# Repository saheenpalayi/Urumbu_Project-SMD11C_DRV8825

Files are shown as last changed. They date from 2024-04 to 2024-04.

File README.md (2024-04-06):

# Urumbu_Project-SMD11C_DRV8825

I wanted to try out the Urumbu Project by Neil Gershenfeld, at SuperFablab Kerala, Kochi but, unfortunately, we don't have a 5V stepper driver in our inventory, so thought of creating a version of the Urumbu project with SAMD11C and DRV8825 motor driver.

## Design
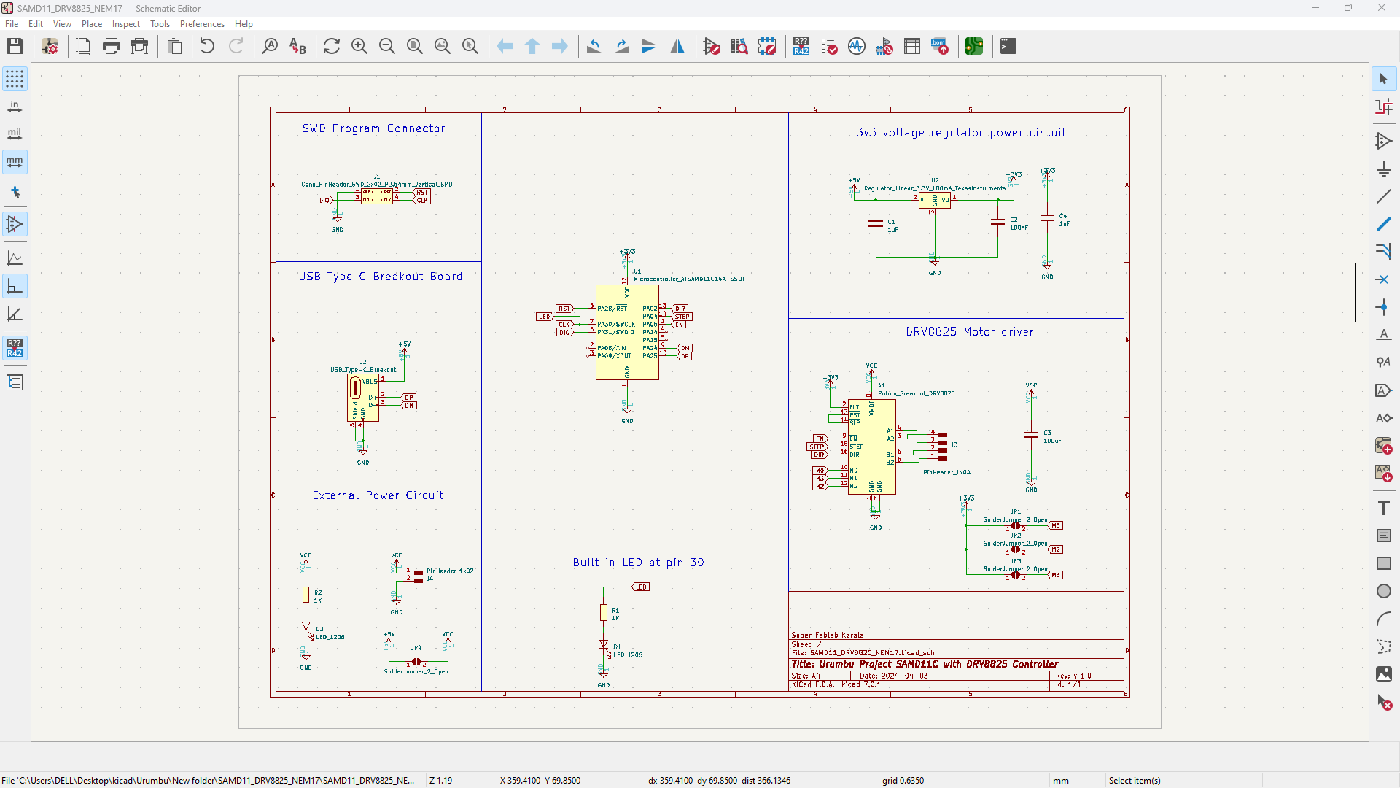
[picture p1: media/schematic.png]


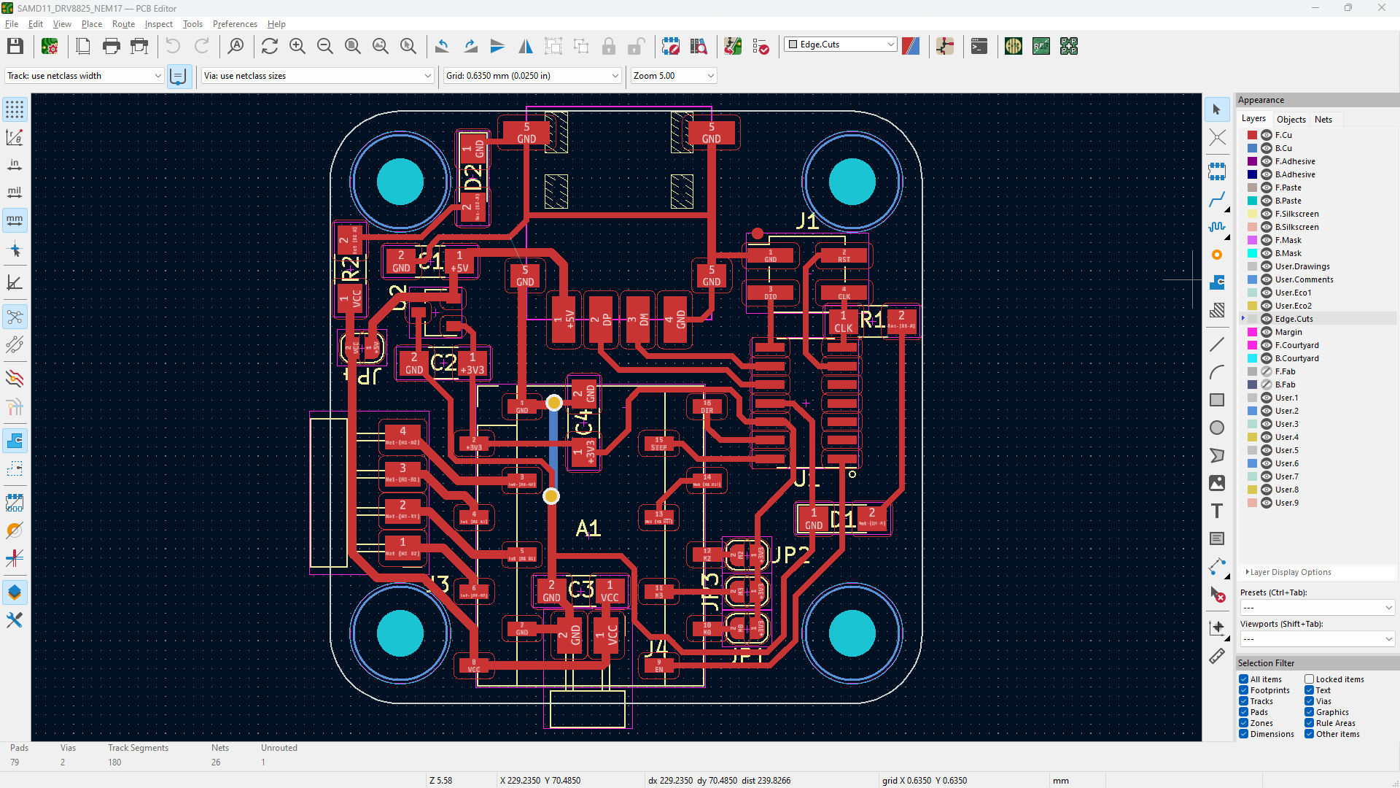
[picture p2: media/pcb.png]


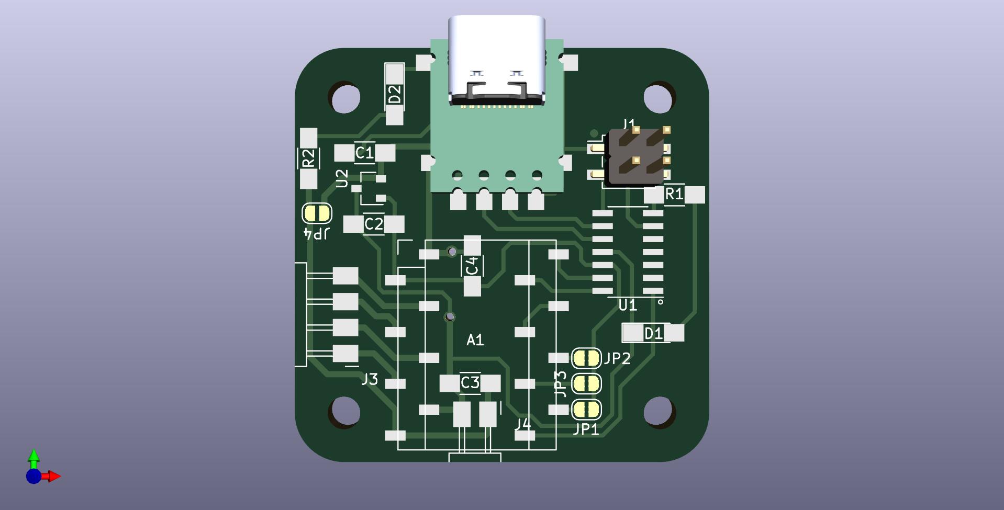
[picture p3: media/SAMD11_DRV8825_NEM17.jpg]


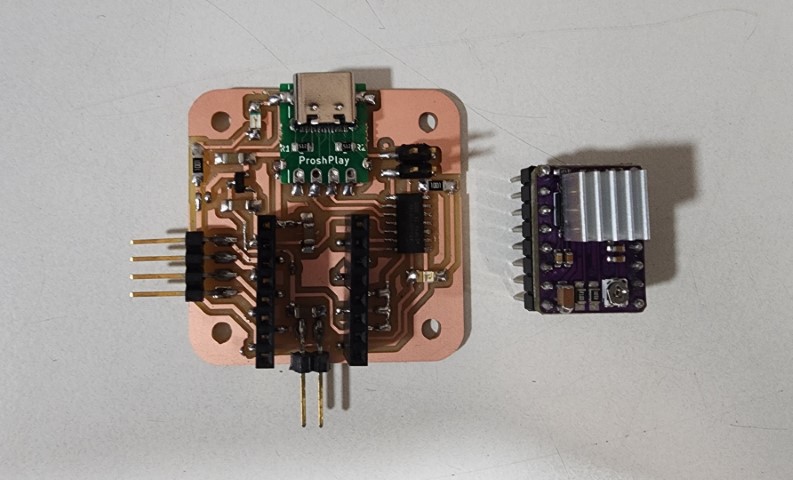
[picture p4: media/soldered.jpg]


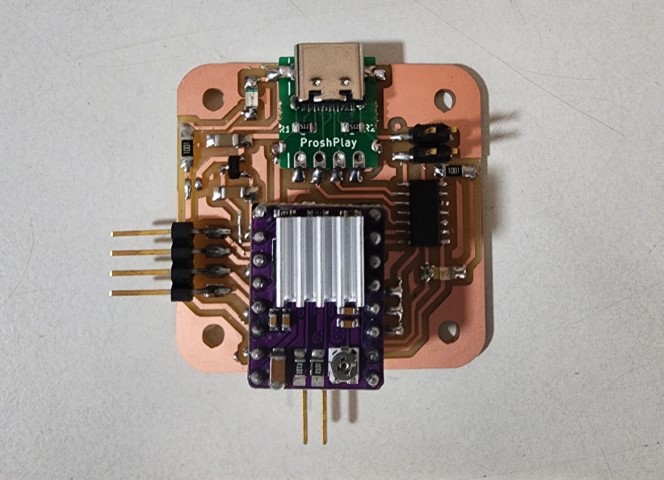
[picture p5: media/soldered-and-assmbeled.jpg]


## Testing

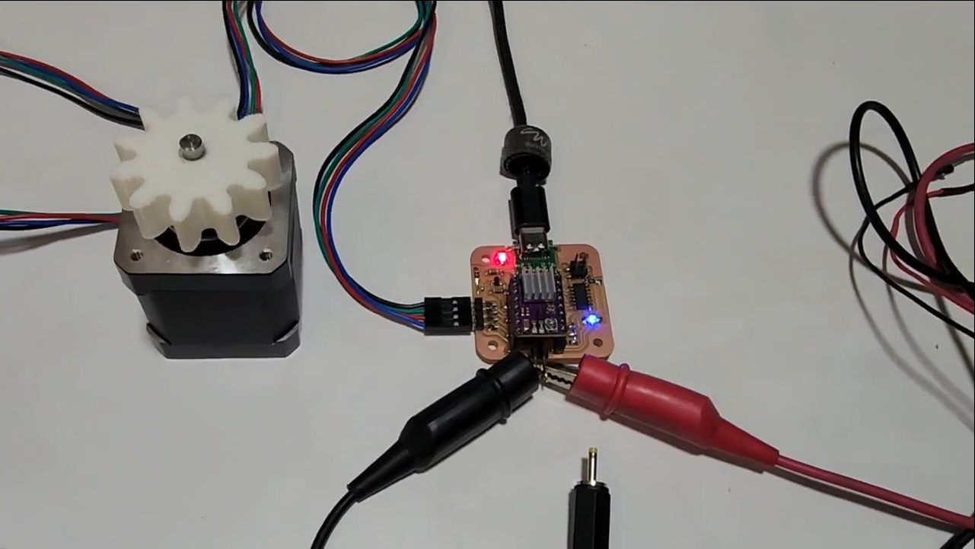
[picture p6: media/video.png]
Watch the video (https://gitlab.fabcloud.org/saheen.palayi/urumbu_project-smd11c_drv8825/-/raw/main/media/Test.mp4)


## Downloads
- [SAMD11_DRV8825_NEM17.pdf](<design files/Kicad Files/SAMD11_DRV8825_NEM17.pdf>)
- [SAMD11_DRV8825_NEM17.step](<design files/Kicad Files/SAMD11_DRV8825_NEM17.step>)
- [gerber.zip](<design files/Gerber Files/gerber.zip>)
- [Firmware](firmware/urumbu-d11c-drv8825/urumbu-d11c-drv8825.ino)

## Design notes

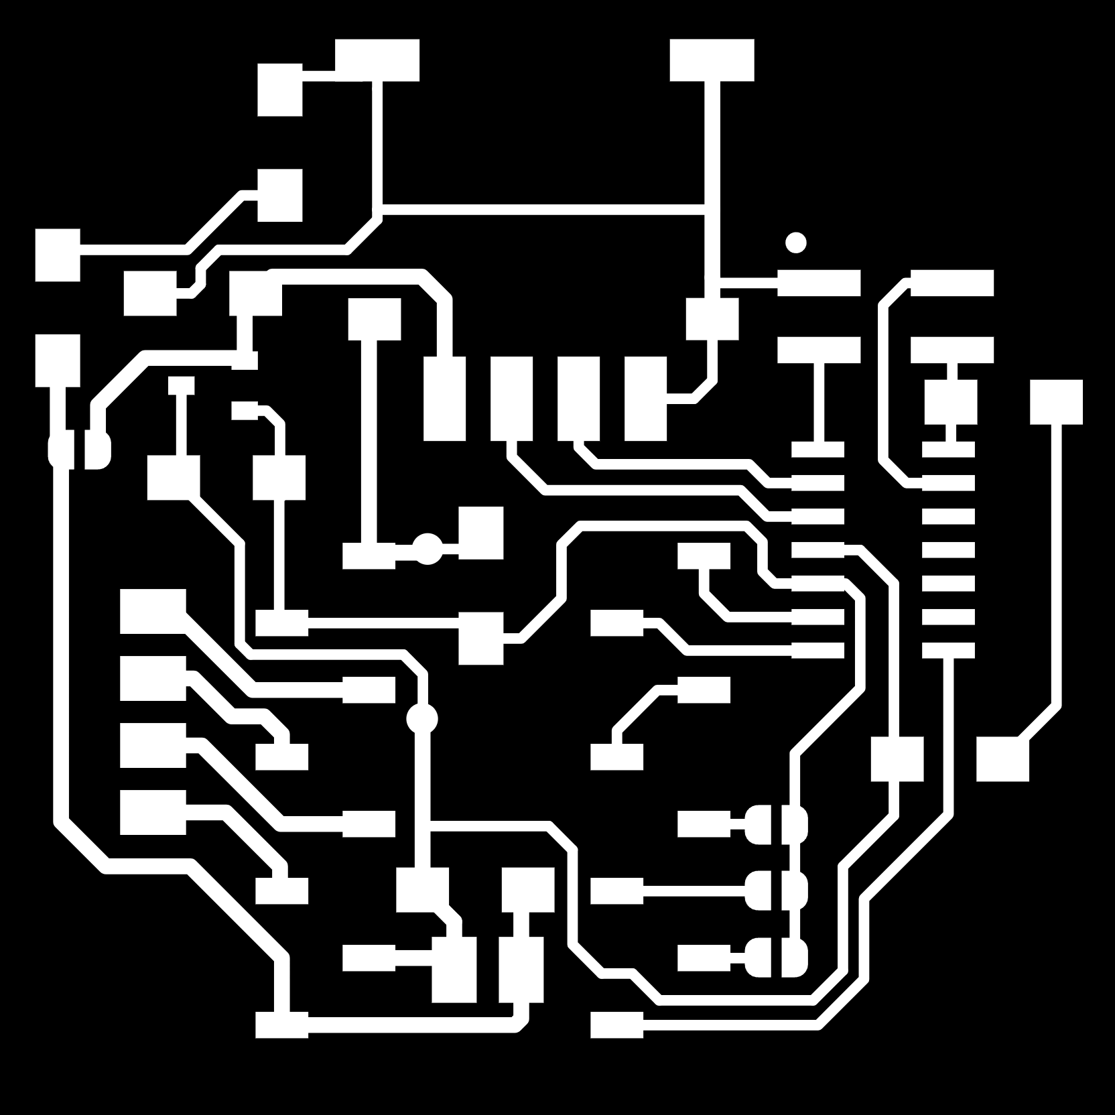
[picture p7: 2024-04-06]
design files/FAB Milling Files/traces.png

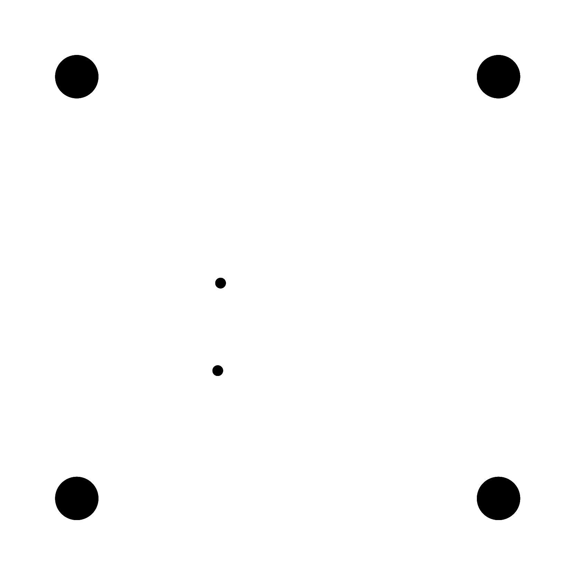
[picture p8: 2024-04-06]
design files/FAB Milling Files/drills.png

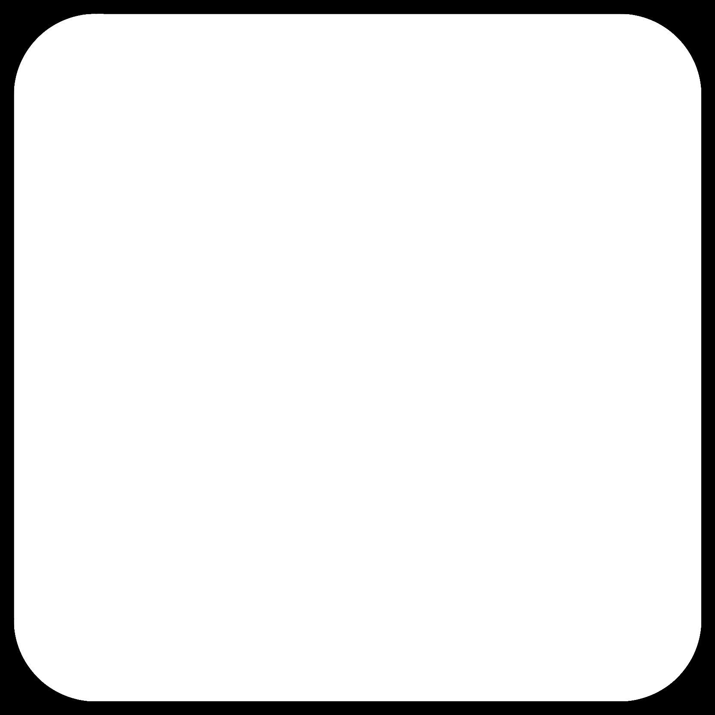
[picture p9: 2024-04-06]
design files/FAB Milling Files/outline.png

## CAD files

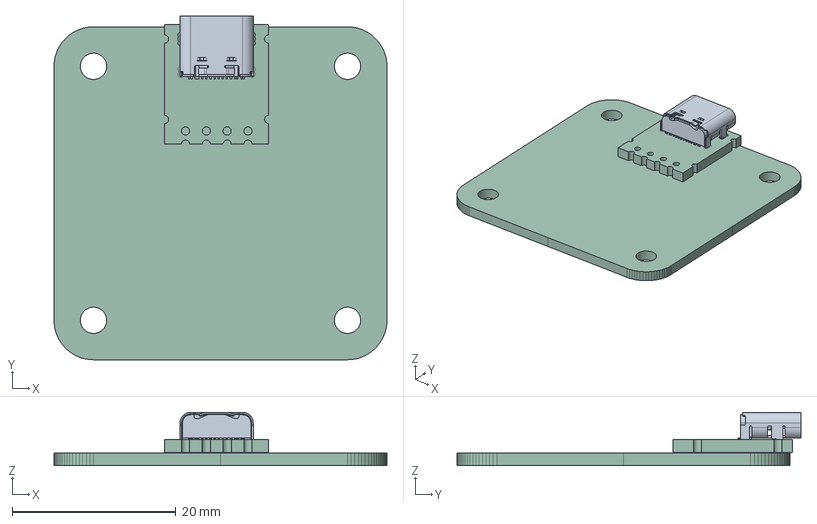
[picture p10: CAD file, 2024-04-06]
design files/Kicad Files/SAMD11_DRV8825_NEM17.step
40.6 x 41.9 x 6.52 mm
PCB

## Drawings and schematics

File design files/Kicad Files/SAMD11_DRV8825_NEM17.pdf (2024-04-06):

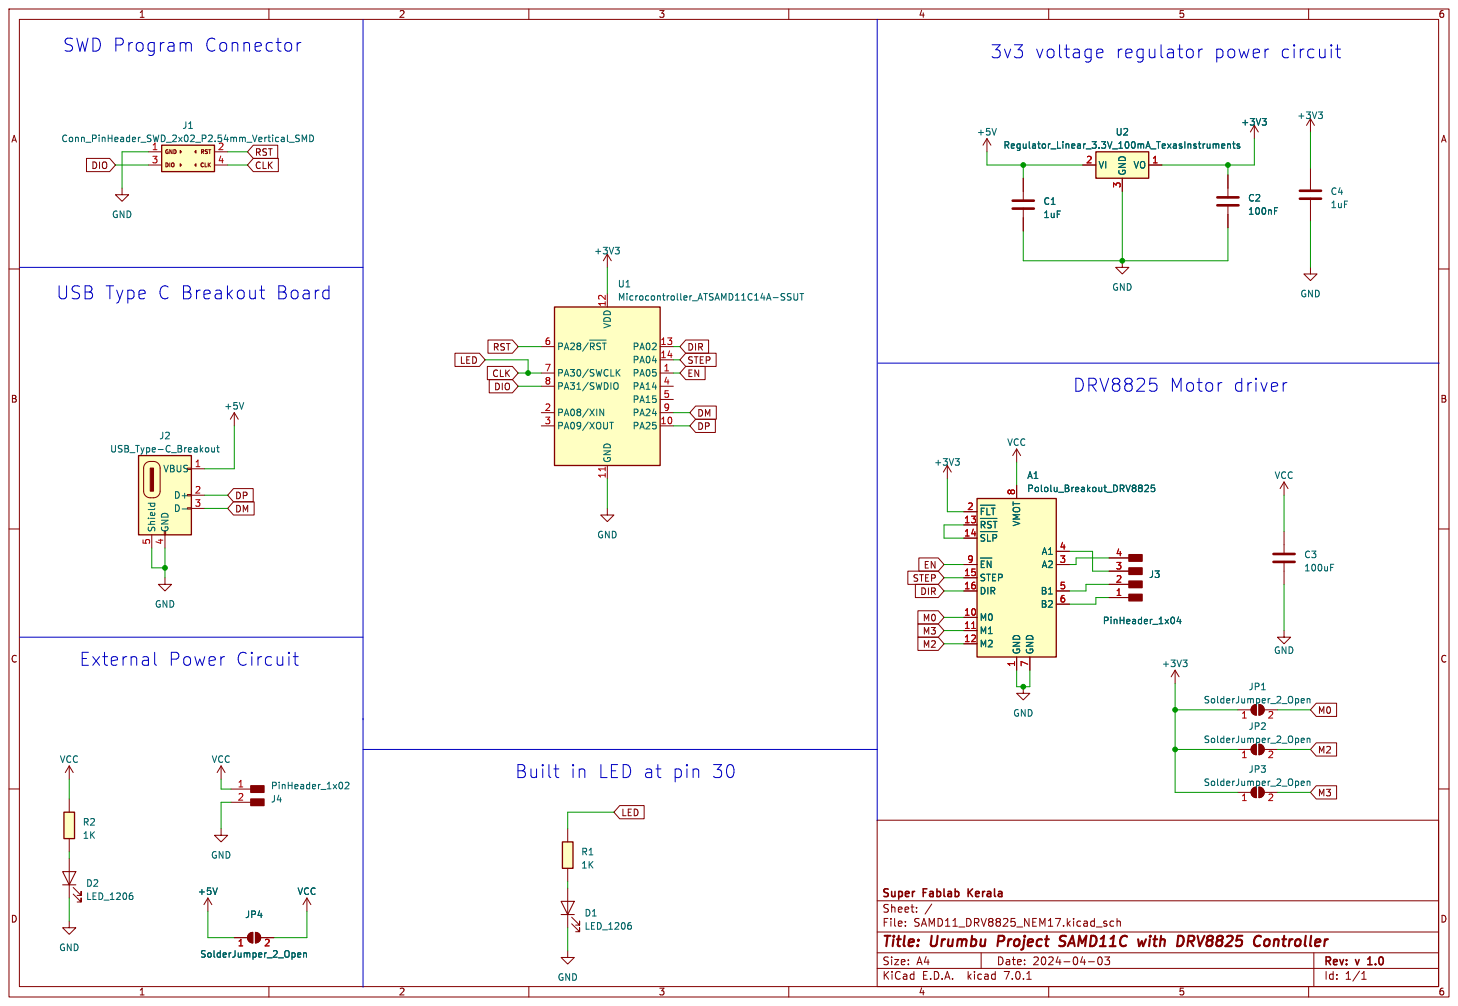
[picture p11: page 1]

USB Type C Breakout Board

1 M0 10 M1 11 M2 12 ~{RST} 13 ~{SLP} 14 STEP 15 DIR 16 ~{FLT} 2 A2 3 A1 4 B1 5 B2 6 GND

Built in LED at pin 30

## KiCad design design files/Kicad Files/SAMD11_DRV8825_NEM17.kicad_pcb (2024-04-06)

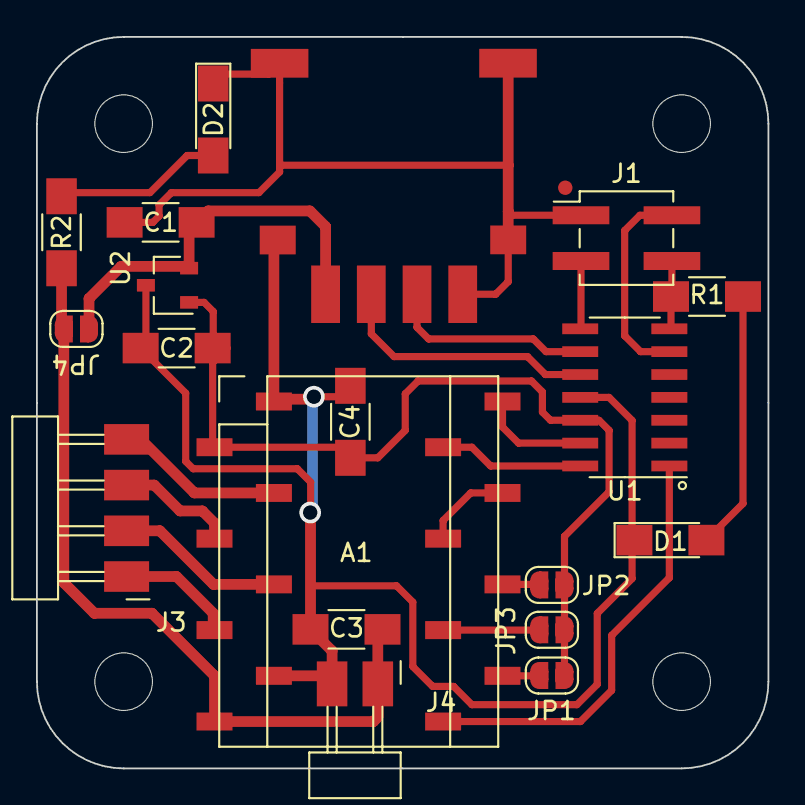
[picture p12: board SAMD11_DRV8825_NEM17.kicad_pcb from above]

Board: 2 copper layers, 40.6 x 40.6 mm, 19 parts (0 on the bottom side), 22 nets.

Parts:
A1: Pololu_Breakout_DRV8825; DRV8825_SMD_pinheader_breakout
C1, C2, C3, C4: C_1206
D1, D2: LED_1206
J1: Conn_PinHeader_SWD_2x02_P2.54mm_Vertical_SMD; PinHeader_2x02_P2.54mm_Vertical_SMD
J2: USB_Type-C_Breakout; ProshPlay-Type-C-breakout-board
J3: Conn_PinHeader_1x04_P2.54mm_Horizontal_SMD; PinHeader_1x04_P2.54mm_Horizontal_SMD
J4: Conn_PinHeader_1x02_P2.54mm_Horizontal_SMD; PinHeader_1x02_P2.54mm_Horizontal_SMD
JP1, JP2, JP3, JP4: SolderJumper_2_Open; SolderJumper-2_P1.3mm_Open_RoundedPad1.0x1.5mm_0.4mm
R1, R2: R_1206
U1: Microcontroller_ATSAMD11C14A-SSUT; SOIC-14_3.9x8.7mm_P1.27mm
U2: Regulator_Linear_3.3V_100mA_TexasInstruments; SOT-23-3

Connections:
+3V3: A1.2 (~FLT), C2.1, C4.1, JP1.1 (A), JP2.1 (A), JP3.1 (A), U1.12 (VDD), U2.1 (VO)
+5V: C1.1, J2.1 (VBUS), JP4.1 (A), U2.2 (VI)
CLK: J1.4, R1.1, U1.7 (PA30/SWCLK)
DIO: J1.3, U1.8 (PA31/SWDIO)
DIR: A1.16 (DIR), U1.13 (PA02)
DM: J2.3 (D-), U1.9 (PA24)
DP: J2.2 (D+), U1.10 (PA25)
EN: A1.9 (~EN), U1.1 (PA05)
GND: A1.1 (GND), A1.7 (GND), C1.2, C2.2, C3.2, C4.2, D1.1 (K), D2.1 (K), J1.1, J2.4 (GND), J2.5 (Shield), J4.2, U1.11 (GND), U2.3 (GND)
M0: A1.10 (M0), JP1.2 (B)
M2: A1.12 (M2), JP2.2 (B)
M3: A1.11 (M1), JP3.2 (B)
unnamed: A1.4 (A1), J3.3
unnamed: A1.3 (A2), J3.4
unnamed: A1.5 (B1), J3.2
unnamed: A1.6 (B2), J3.1
unnamed: A1.13 (~RST), A1.14 (~SLP)
unnamed: D1.2 (A), R1.2
unnamed: D2.2 (A), R2.2
RST: J1.2, U1.6 (PA28/~RST)
STEP: A1.15 (STEP), U1.14 (PA04)
VCC: A1.8 (VMOT), C3.1, J4.1, JP4.2 (B), R2.1

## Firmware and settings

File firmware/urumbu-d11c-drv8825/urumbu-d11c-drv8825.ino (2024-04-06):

//
// urumbu-d11c-drv8825.ino
//
// serial step-and-direction
//
// Neil Gershenfeld 4/11/21
// Quentin Bolsee 12/7/21 : add button
// Saheen Palayi 06/04/2024 : removed microstepping and added LED, 
//
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


#define Address "000" // change address here

#define LED 30
#define EN 5
#define DIR 2
#define STEP 4
#define BUTTON 31


void setup() {
  SerialUSB.begin(0);

  pinMode(LED, OUTPUT);
  pinMode(EN, OUTPUT);
  pinMode(STEP, OUTPUT);
  pinMode(DIR, OUTPUT);
  pinMode(BUTTON, INPUT_PULLUP);

  digitalWrite(LED, HIGH);
  digitalWrite(EN, HIGH);
  digitalWrite(STEP, LOW);
  digitalWrite(DIR, LOW);
}

void loop() {
  if (SerialUSB.available()) {
    char c = SerialUSB.read();
    if (c == 'f') {
      digitalWrite(DIR, HIGH);
      digitalWrite(STEP, HIGH);
      digitalWrite(LED, HIGH);
      delayMicroseconds(2);
      digitalWrite(STEP, LOW);
      digitalWrite(LED, LOW);
    } else if (c == 'r') {
      digitalWrite(DIR, LOW);
      digitalWrite(LED, HIGH);
      delayMicroseconds(2);
      digitalWrite(STEP, LOW);
      digitalWrite(LED, LOW);
    } else if (c == '?') {
      // reply with button value
      int btn = digitalRead(BUTTON);
      SerialUSB.write(btn ? '1' : '0');
    } else if (c == '@') {
      SerialUSB.write(Address); 
    }
  }
}

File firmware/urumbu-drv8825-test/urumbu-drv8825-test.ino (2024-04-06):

//
// urumbu-drv8825-test.ino
//
// DRV8825-D11C stepper test code
//
// Saheen Palayi 06/04/24
//
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

#define LED 30
#define EN 5
#define DIR 2
#define STEP 4

void setup() {
  pinMode(LED, OUTPUT);   // LED pin as output
  pinMode(EN, OUTPUT);    // Enable pin as output
  pinMode(DIR, OUTPUT);   // Direction pin as output
  pinMode(STEP, OUTPUT);  // Step pin as output
}

void loop() {
  digitalWrite(LED, HIGH);  // Turn on LED to indicate motor is running

  digitalWrite(EN, LOW);    // Enable the motor driver
  digitalWrite(DIR, HIGH);  // Set direction to clockwise

  // Rotate motor
  for (int i = 0; i < 200; i++) {  // 200 steps for one complete revolution
    digitalWrite(STEP, HIGH);      // Step high
    delayMicroseconds(500);        // Wait 0.5ms
    digitalWrite(STEP, LOW);       // Step low
    delayMicroseconds(500);        // Wait 0.5ms
  }

  digitalWrite(EN, HIGH);  // Disable the motor driver
  digitalWrite(LED, LOW);  // Turn off LED
  delay(1000);             // Wait for 1 second before next rotation
}
